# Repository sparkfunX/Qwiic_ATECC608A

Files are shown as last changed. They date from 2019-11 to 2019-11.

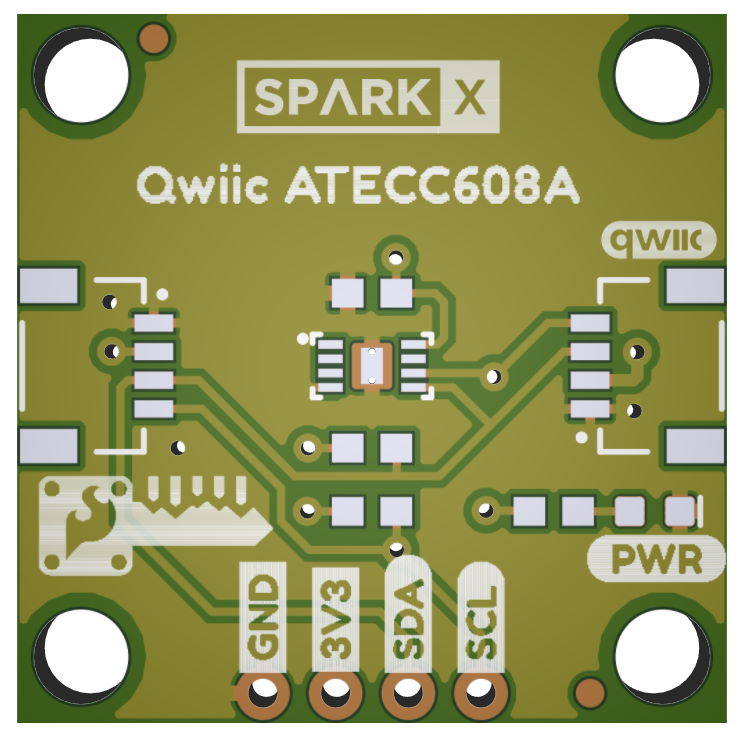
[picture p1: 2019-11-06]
Documentation/qwiic_atecc608a.jpg

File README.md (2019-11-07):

SparkFun Cryptographic Co-Processor Breakout - ATECC608A (Qwiic)
========================================

Qwiic ATECC608A (https://www.sparkfun.com/products/15838)

[*SparkFun Cryptographic Co-Processor Breakout - ATECC608A (Qwiic) (SPX-15838)*](https://www.sparkfun.com/products/15838)

The SparkX ATECC608A Cryptographic Co-processor Breakout allows you to add strong security to your IoT node, edge device, or embedded system. This includes <strong><u>a</u>symmetric</strong> authentication, <strong>symetric</strong> AES-128 encryption/decryption, and much more. Note, the ATECC608A has limited Arduino support and the complete datasheet is under NDA with Microchip.

This breakout board includes two Qwiic ports for plug and play functionality. Utilizing our handy Qwiic system, no soldering is required to connect it to the rest of your system. However, we still have broken out 0.1"-spaced pins in case you prefer to use a breadboard. The ATECC608A chip is capable of many cryptographic processes, including, but not limited to:

* Creating and securely storing unique asymmetric key pairs based on Elliptic Curve Cryptography (FIPS186-3).
* AES-128: Encrypt/Decrypt, Galois Field Multiply for GCM
* Creating and verifying 64-byte digital signatures (from 32-bytes of message data).
* Creating a shared secret key on a public channel via Elliptic Curve Diffie-Hellman Algorithm.
* SHA-256 & HMAC Hash including off-chip context save/restore
* Internal high quality FIPS random number generator. 

Repository Contents
-------------------

* **/Documentation** - Data sheets, additional product information
* **/Hardware** - Eagle design files (.brd, .sch)
* **/Production** - Production panel files (.brd)

Documentation
--------------
* [Schematic](https://cdn.sparkfun.com/assets/c/7/e/b/e/Qwiic_ATECC608A_SCHEMATIC.pdf)
* [Eagle Files](https://cdn.sparkfun.com/assets/1/9/5/f/5/Qwiic_ATECC608A.zip)
* [Board Dimensions](https://cdn.sparkfun.com/assets/7/7/3/9/5/Qwiic_ATECC608A_Dimensions.pdf)
* [Github Hardware Repo](https://github.com/sparkfunx/Qwiic_ATECC608A)
* [Datasheet Summary (ATECC608A)](https://cdn.sparkfun.com/assets/d/5/c/c/a/ATECC608A-CryptoAuthentication-Device-Summary-Data-Sheet-DS40001977B.pdf) Note, this is not the complete datasheet, which is under NDA with Microchip.
* [ArduinoECCX08 Arduino Library](https://github.com/arduino-libraries/ArduinoECCX08)
* [CryptoAuthLib - Microchip CryptoAuthentication Library (includes python support)](https://github.com/MicrochipTech/cryptoauthlib)
* [Microchip ATECC608A Product page](https://www.microchip.com/wwwproducts/en/ATECC608A)

License Information
-------------------

This product is _**open source**_! 

Please review the LICENSE.md file for license information. 

If you have any questions or concerns on licensing, please contact technical support on our [SparkFun forums](https://forum.sparkfun.com/viewforum.php?f=152).

Distributed as-is; no warranty is given.

- Your friends at SparkFun.

_<COLLABORATION CREDIT>_

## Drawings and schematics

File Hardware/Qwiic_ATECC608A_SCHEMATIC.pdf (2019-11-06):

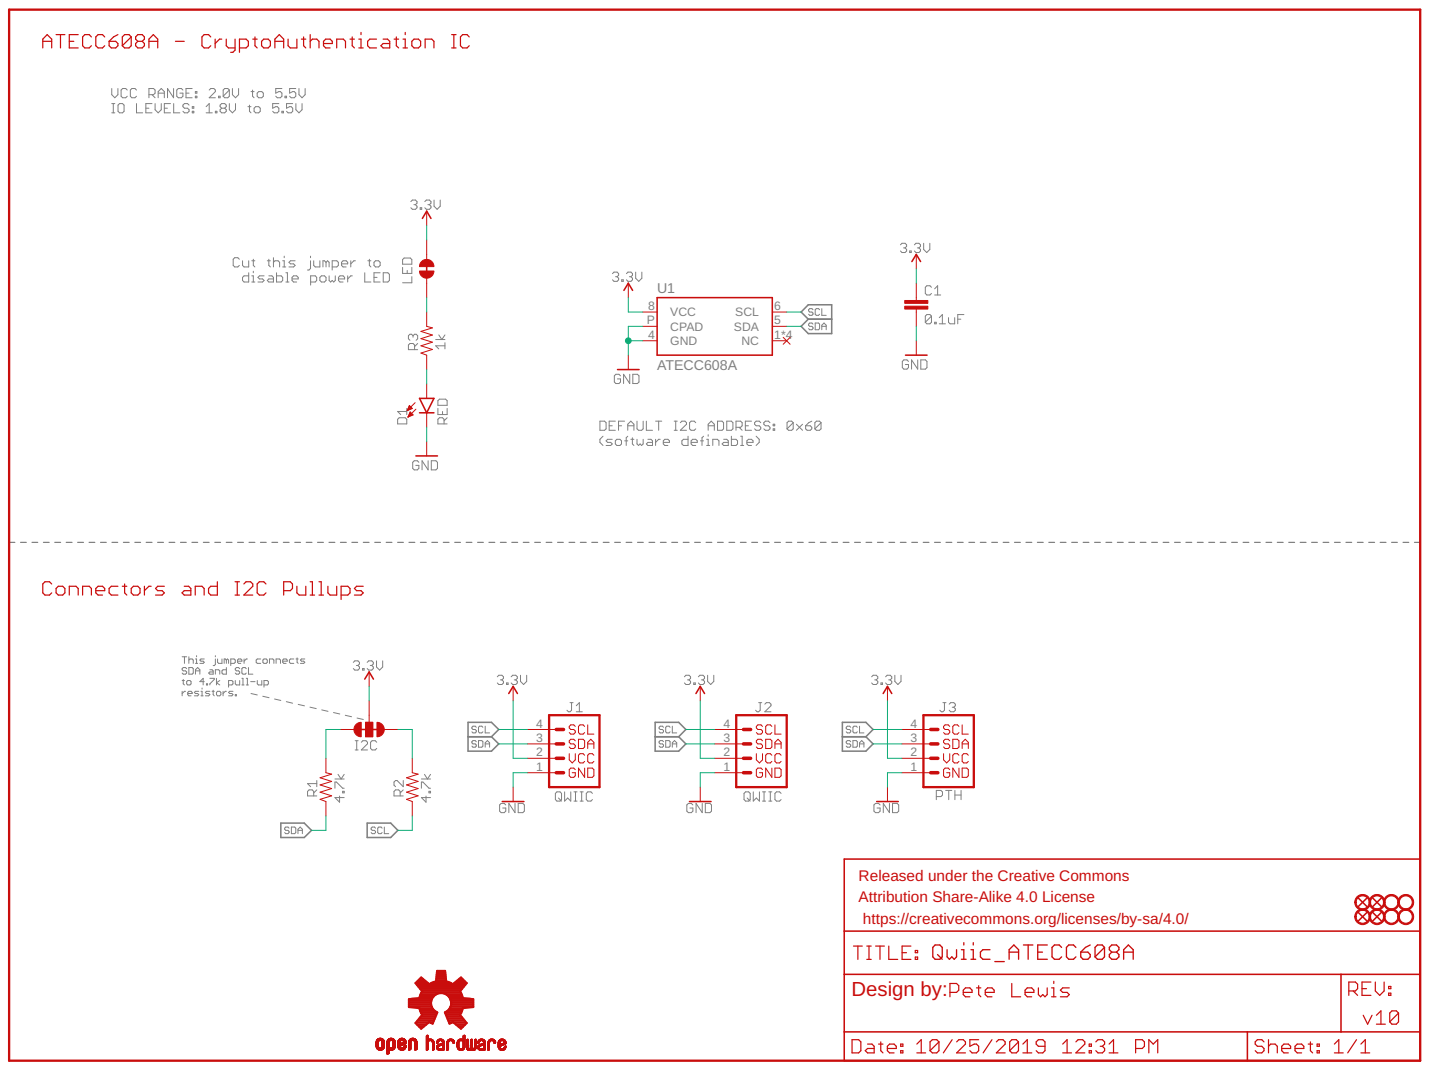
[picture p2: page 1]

Released under the Creative Commons
Attribution Share-Alike 4.0 License
https://creativecommons.org/licenses/by-sa/4.0/

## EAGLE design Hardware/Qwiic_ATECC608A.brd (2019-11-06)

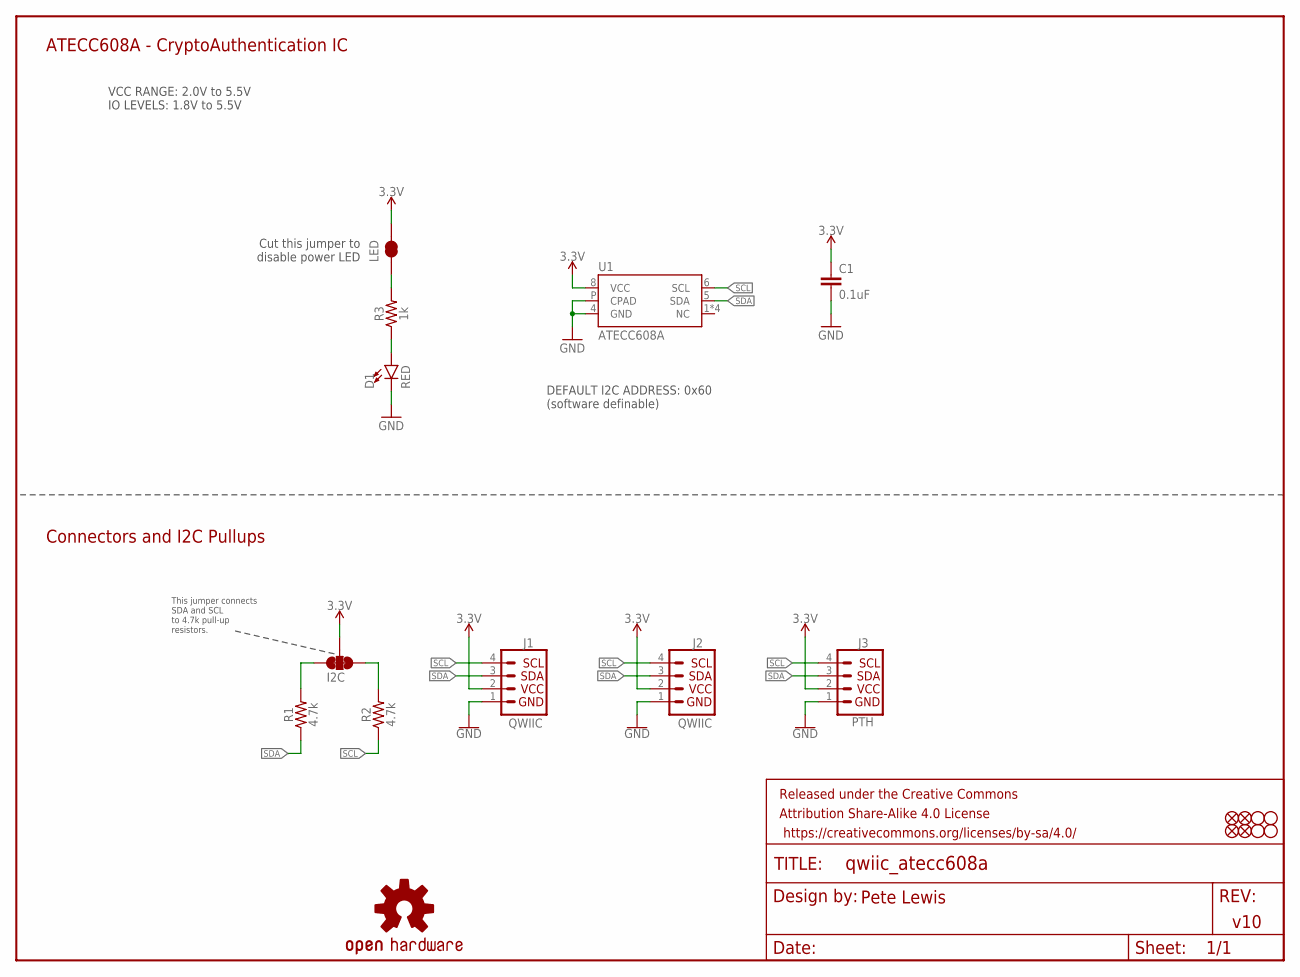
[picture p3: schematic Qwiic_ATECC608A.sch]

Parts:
C1: 0.1uF; 0603
D1: RED; LED-0603
FD1, FD2, FD3, FD4: FIDUCIAL1X2; FIDUCIAL-1X2
FRAME1: FRAME-LETTER; CREATIVE_COMMONS
H1, H2, H3, H4: STAND-OFF
I2C: JUMPER-SMT_3_2-NC_TRACE_SILK; SMT-JUMPER_3_2-NC_TRACE_SILK
J1, J2: QWIIC; JST04_1MM_RA
J3: PTH; 1X04_NO_SILK
LED: JUMPER-SMT_2_NC_TRACE_SILK; SMT-JUMPER_2_NC_TRACE_SILK
LOGO4: OSHW-LOGOS; OSHW-LOGO-S
R1, R2: 4.7k; 0603
R3: 1k; 0603
U1: ATECC608A; UDFN_2X3MM

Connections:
3.3V: C1.1, I2C.2, J1.2, J2.2, J3.2, LED.2, U1.8 (VCC)
GND: C1.2, D1.C, J1.1, J2.1, J3.1, U1.4 (GND), U1.P (CPAD)
unnamed: D1.A, R3.1
unnamed: I2C.3, R1.2
unnamed: I2C.1, R2.2
unnamed: LED.1, R3.2
SCL: J1.4, J2.4, J3.4, R2.1, U1.6 (SCL)
SDA: J1.3, J2.3, J3.3, R1.1, U1.5 (SDA)

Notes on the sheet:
This jumper connects SDA and SCL to 4.7k pull-up resistors.
v10
Pete Lewis
ATECC608A - CryptoAuthentication IC
VCC RANGE: 2.0V to 5.5V IO LEVELS: 1.8V to 5.5V
Connectors and I2C Pullups
Cut this jumper to disable power LED
DEFAULT I2C ADDRESS: 0x60 (software definable)

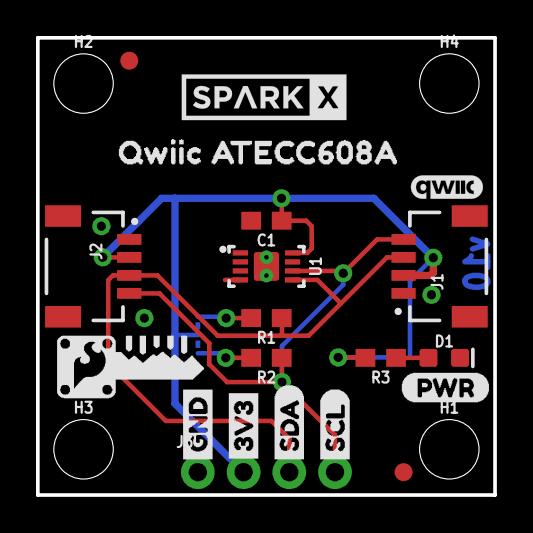
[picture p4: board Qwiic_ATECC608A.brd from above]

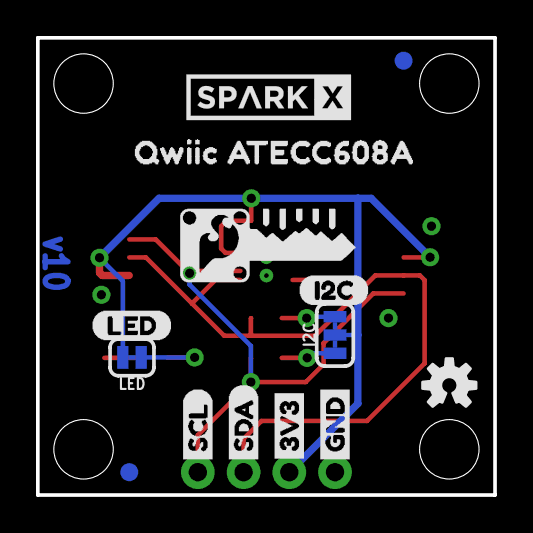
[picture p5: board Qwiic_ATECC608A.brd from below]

Board: 2 copper layers, 25.4 x 25.4 mm, 39 parts (14 on the bottom side), 8 nets.

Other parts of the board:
U$1: LED0
U$2, U$7: 3V34
U$3, U$5: SDA5
U$4, U$8: GND3
U$6, U$10: SCL6
U$9, U$19: SPARKX-MEDIUM
U$11, U$12: QWIIC_ATECC608A0
U$13: PWR0
U$15, U$18: CRYPTO_COPROCESSOR_LOGO#04#PNG
U$16: QWIIC_4MM
U$22: I2C0

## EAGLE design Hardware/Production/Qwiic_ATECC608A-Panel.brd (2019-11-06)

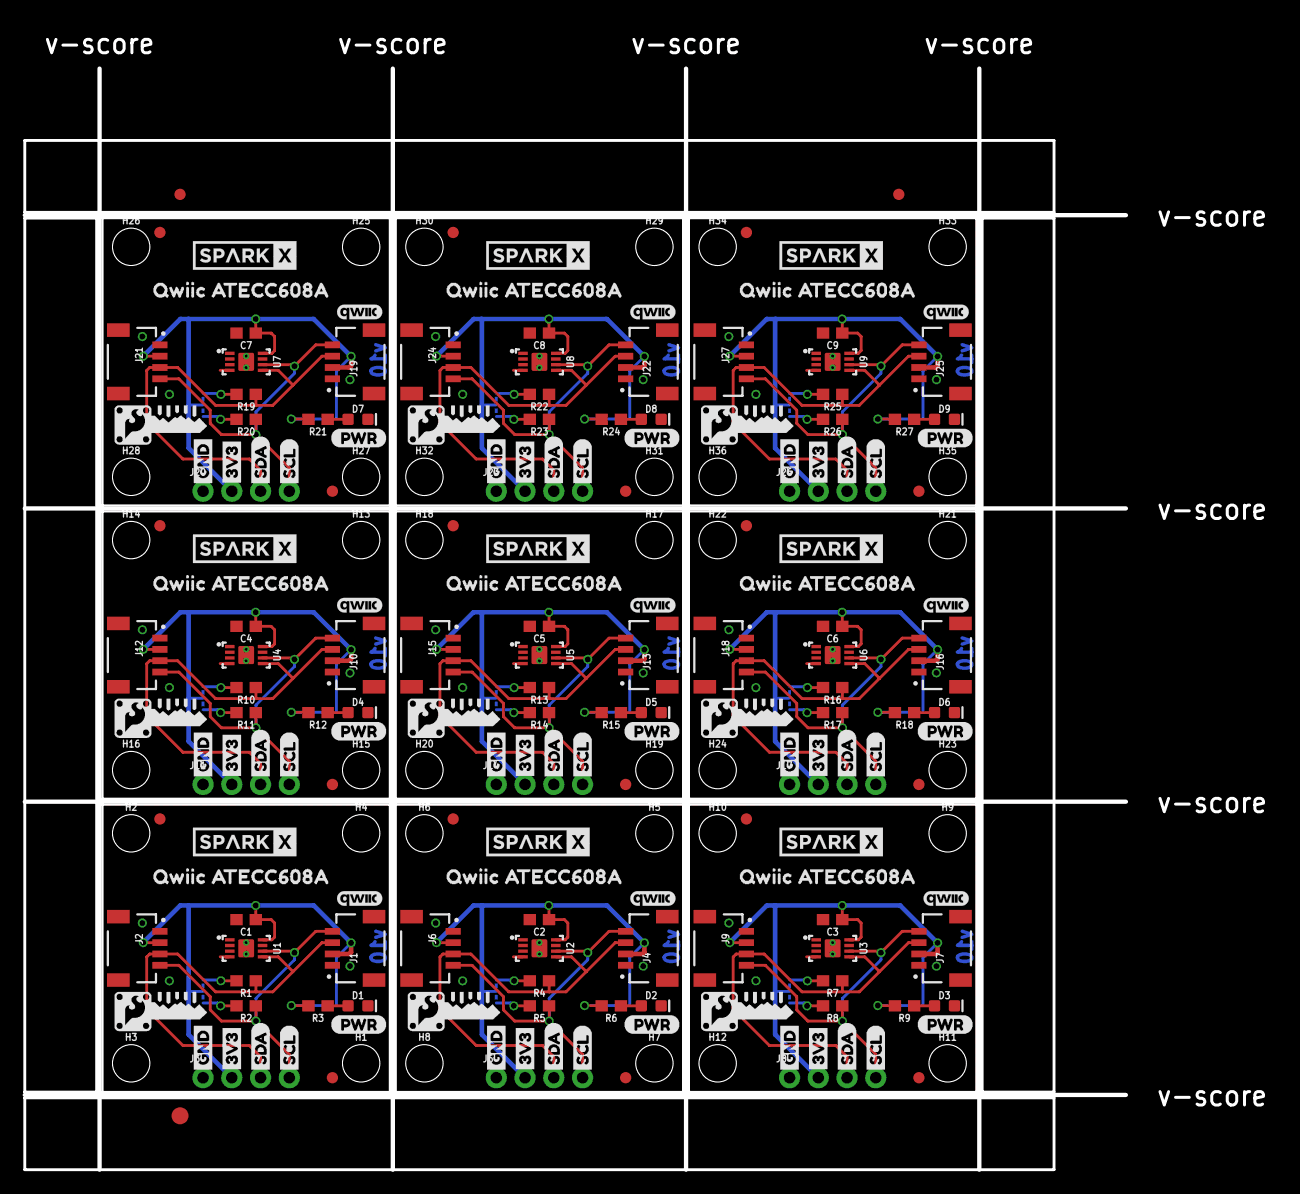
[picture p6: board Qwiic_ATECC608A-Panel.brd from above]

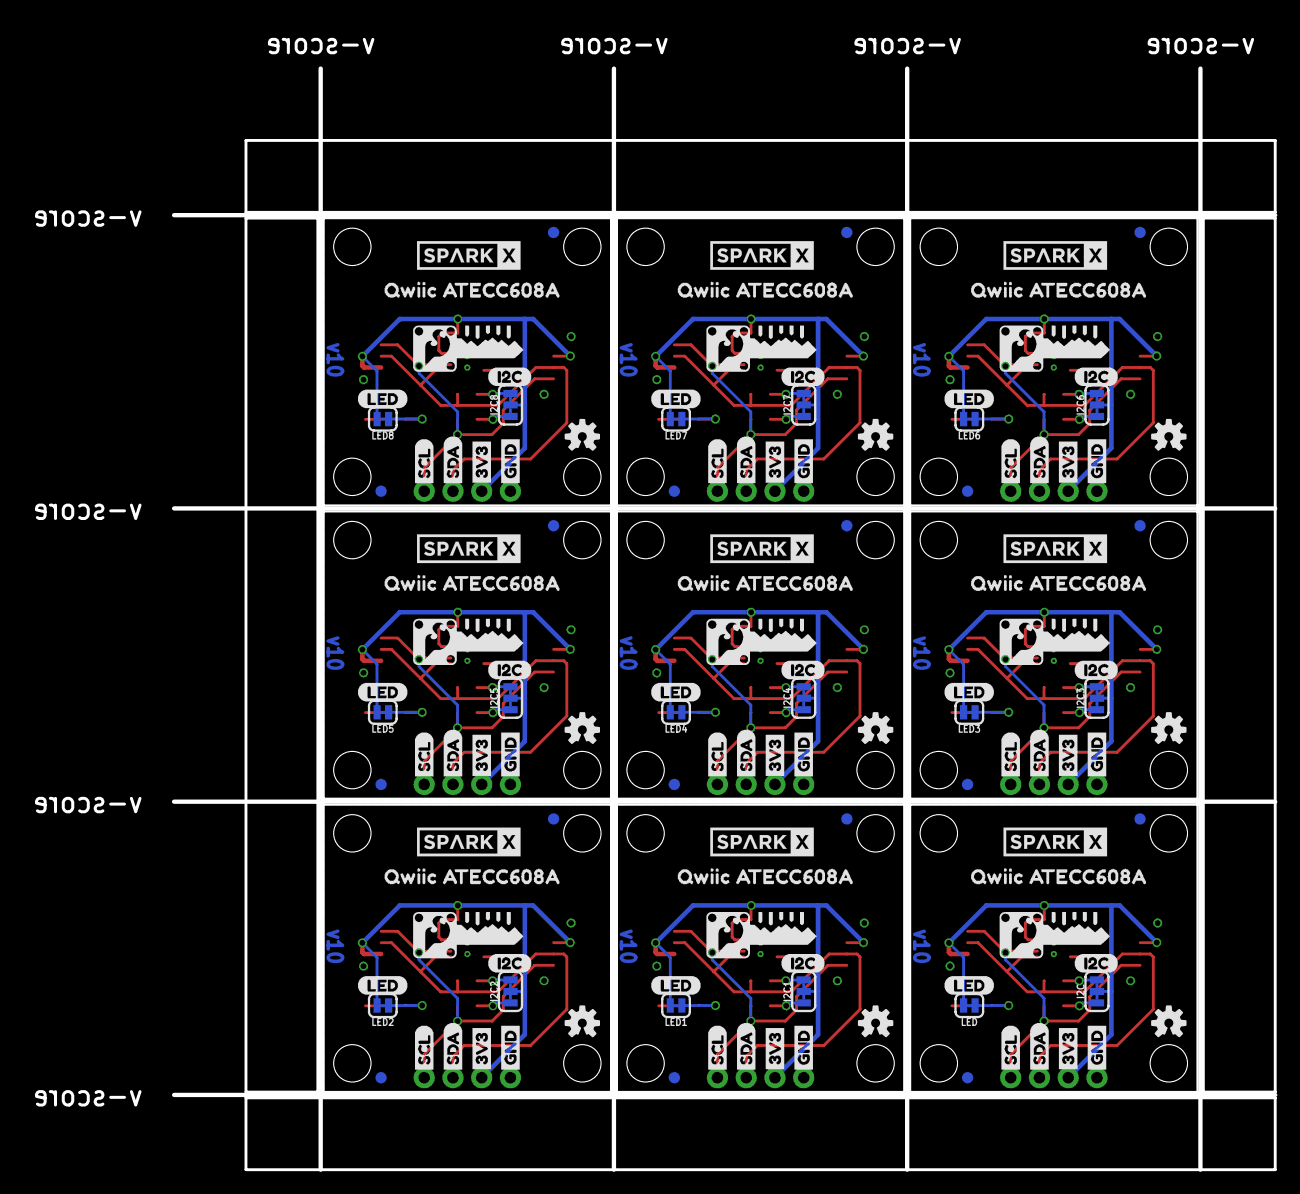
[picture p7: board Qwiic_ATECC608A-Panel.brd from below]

Board: 2 copper layers, 97.3 x 97.3 mm, 345 parts (126 on the bottom side), 72 nets.

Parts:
C1, C2, C3, C4, C5, C6, C7, C8, C9: 0.1uF; 0603
D1, D2, D3, D4, D5, D6, D7, D8, D9: RED; LED-0603
E$1, E$2: FIDUCIAL-1X2
E$3: FIDUCIAL-1.5X3
FD1, FD2, FD3, FD4, FD5, FD6, FD7, FD8, FD9, FD10, FD11, FD12, FD13, FD14, FD15, FD16, FD17, FD18, FD19, FD20, FD21, FD22, FD23, FD24, FD25, FD26, FD27, FD28, FD29, FD30, FD31, FD32, FD33, FD34, FD35, FD36: FIDUCIAL1X2; FIDUCIAL-1X2
H1, H2, H3, H4, H5, H6, H7, H8, H9, H10, H11, H12, H13, H14, H15, H16, H17, H18, H19, H20, H21, H22, H23, H24, H25, H26, H27, H28, H29, H30, H31, H32, H33, H34, H35, H36: STAND-OFF
I2C, I2C1, I2C2, I2C3, I2C4, I2C5, I2C6, I2C7, I2C8: SMT-JUMPER_3_2-NC_TRACE_SILK
J1, J2, J4, J6, J7, J9, J10, J12, J13, J15, J16, J18, J19, J21, J22, J24, J25, J27: QWIIC; JST04_1MM_RA
J3, J5, J8, J11, J14, J17, J20, J23, J26: PTH; 1X04_NO_SILK
LED, LED1, LED2, LED3, LED4, LED5, LED6, LED7, LED8: SMT-JUMPER_2_NC_TRACE_SILK
LOGO1, LOGO2, LOGO3, LOGO4, LOGO5, LOGO6, LOGO7, LOGO8, LOGO9: OSHW-LOGOS; OSHW-LOGO-S
R1, R2, R4, R5, R7, R8, R10, R11, R13, R14, R16, R17, R19, R20, R22, R23, R25, R26: 4.7k; 0603
R3, R6, R9, R12, R15, R18, R21, R24, R27: 1k; 0603
U1, U2, U3, U4, U5, U6, U7, U8, U9: ATECC608A; UDFN_2X3MM
U$1, U$28, U$46, U$64, U$82, U$100, U$118, U$136, U$154: LED0
U$2, U$7, U$21, U$26, U$40, U$44, U$58, U$62, U$76, U$80, U$94, U$98, U$112, U$116, U$130, U$134, U$148, U$152: 3V34
U$3, U$5, U$24, U$29, U$42, U$47, U$60, U$65, U$78, U$83, U$96, U$101, U$114, U$119, U$132, U$137, U$150, U$155: SDA5
U$4, U$8, U$23, U$27, U$41, U$45, U$59, U$63, U$77, U$81, U$95, U$99, U$113, U$117, U$131, U$135, U$149, U$153: GND3
U$6, U$10, U$25, U$30, U$43, U$48, U$61, U$66, U$79, U$84, U$97, U$102, U$115, U$120, U$133, U$138, U$151, U$156: SCL6
U$9, U$19, U$33, U$34, U$51, U$52, U$69, U$70, U$87, U$88, U$105, U$106, U$123, U$124, U$141, U$142, U$159, U$160: SPARKX-MEDIUM
U$11, U$12, U$35, U$36, U$53, U$54, U$71, U$72, U$89, U$90, U$107, U$108, U$125, U$126, U$143, U$144, U$161, U$162: QWIIC_ATECC608A0
U$13, U$17, U$38, U$56, U$74, U$92, U$110, U$128, U$146: PWR0
U$14, U$16, U$37, U$55, U$73, U$91, U$109, U$127, U$145: QWIIC_4MM
U$15, U$18, U$31, U$32, U$49, U$50, U$67, U$68, U$85, U$86, U$103, U$104, U$121, U$122, U$139, U$140, U$157, U$158: CRYPTO_COPROCESSOR_LOGO#04#PNG
U$20, U$22, U$39, U$57, U$75, U$93, U$111, U$129, U$147: I2C0

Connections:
3.3V: C1.1, I2C.2, J1.2, J2.2, J3.2, LED.2, U1.8
3.3V1: C2.1, I2C1.2, J4.2, J5.2, J6.2, LED1.2, U2.8
3.3V2: C3.1, I2C2.2, J7.2, J8.2, J9.2, LED2.2, U3.8
3.3V3: C4.1, I2C3.2, J10.2, J11.2, J12.2, LED3.2, U4.8
3.3V4: C5.1, I2C4.2, J13.2, J14.2, J15.2, LED4.2, U5.8
3.3V5: C6.1, I2C5.2, J16.2, J17.2, J18.2, LED5.2, U6.8
3.3V6: C7.1, I2C6.2, J19.2, J20.2, J21.2, LED6.2, U7.8
3.3V7: C8.1, I2C7.2, J22.2, J23.2, J24.2, LED7.2, U8.8
3.3V8: C9.1, I2C8.2, J25.2, J26.2, J27.2, LED8.2, U9.8
GND: C1.2, D1.C, J1.1, J2.1, J3.1, U1.4, U1.P
GND1: C2.2, D2.C, J4.1, J5.1, J6.1, U2.4, U2.P
GND2: C3.2, D3.C, J7.1, J8.1, J9.1, U3.4, U3.P
GND3: C4.2, D4.C, J10.1, J11.1, J12.1, U4.4, U4.P
GND4: C5.2, D5.C, J13.1, J14.1, J15.1, U5.4, U5.P
GND5: C6.2, D6.C, J16.1, J17.1, J18.1, U6.4, U6.P
GND6: C7.2, D7.C, J19.1, J20.1, J21.1, U7.4, U7.P
GND7: C8.2, D8.C, J22.1, J23.1, J24.1, U8.4, U8.P
GND8: C9.2, D9.C, J25.1, J26.1, J27.1, U9.4, U9.P
unnamed: I2C1.3, R4.2
unnamed: I2C1.1, R5.2
unnamed: D1.A, R3.1
unnamed: I2C.3, R1.2
unnamed: I2C.1, R2.2
unnamed: D2.A, R6.1
unnamed: LED.1, R3.2
unnamed: LED1.1, R6.2
unnamed: I2C2.3, R7.2
unnamed: I2C2.1, R8.2
unnamed: D3.A, R9.1
unnamed: LED2.1, R9.2
unnamed: I2C3.3, R10.2
unnamed: I2C3.1, R11.2
unnamed: D4.A, R12.1
unnamed: LED3.1, R12.2
unnamed: I2C4.3, R13.2
unnamed: I2C4.1, R14.2
unnamed: D5.A, R15.1
unnamed: LED4.1, R15.2
unnamed: I2C5.3, R16.2
unnamed: I2C5.1, R17.2
unnamed: D6.A, R18.1
unnamed: LED5.1, R18.2
unnamed: I2C6.3, R19.2
unnamed: I2C6.1, R20.2
unnamed: D7.A, R21.1
unnamed: LED6.1, R21.2
unnamed: I2C7.3, R22.2
unnamed: I2C7.1, R23.2
unnamed: D8.A, R24.1
unnamed: LED7.1, R24.2
unnamed: I2C8.3, R25.2
unnamed: I2C8.1, R26.2
unnamed: D9.A, R27.1
unnamed: LED8.1, R27.2
SCL: J1.4, J2.4, J3.4, R2.1, U1.6
SCL1: J4.4, J5.4, J6.4, R5.1, U2.6
SCL2: J7.4, J8.4, J9.4, R8.1, U3.6
SCL3: J10.4, J11.4, J12.4, R11.1, U4.6
SCL4: J13.4, J14.4, J15.4, R14.1, U5.6
SCL5: J16.4, J17.4, J18.4, R17.1, U6.6
SCL6: J19.4, J20.4, J21.4, R20.1, U7.6
SCL7: J22.4, J23.4, J24.4, R23.1, U8.6
SCL8: J25.4, J26.4, J27.4, R26.1, U9.6
SDA: J1.3, J2.3, J3.3, R1.1, U1.5
SDA1: J4.3, J5.3, J6.3, R4.1, U2.5
SDA2: J7.3, J8.3, J9.3, R7.1, U3.5
SDA3: J10.3, J11.3, J12.3, R10.1, U4.5
SDA4: J13.3, J14.3, J15.3, R13.1, U5.5
SDA5: J16.3, J17.3, J18.3, R16.1, U6.5
SDA6: J19.3, J20.3, J21.3, R19.1, U7.5
SDA7: J22.3, J23.3, J24.3, R22.1, U8.5
SDA8: J25.3, J26.3, J27.3, R25.1, U9.5

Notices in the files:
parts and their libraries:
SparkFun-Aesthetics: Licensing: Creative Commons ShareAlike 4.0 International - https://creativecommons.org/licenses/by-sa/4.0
